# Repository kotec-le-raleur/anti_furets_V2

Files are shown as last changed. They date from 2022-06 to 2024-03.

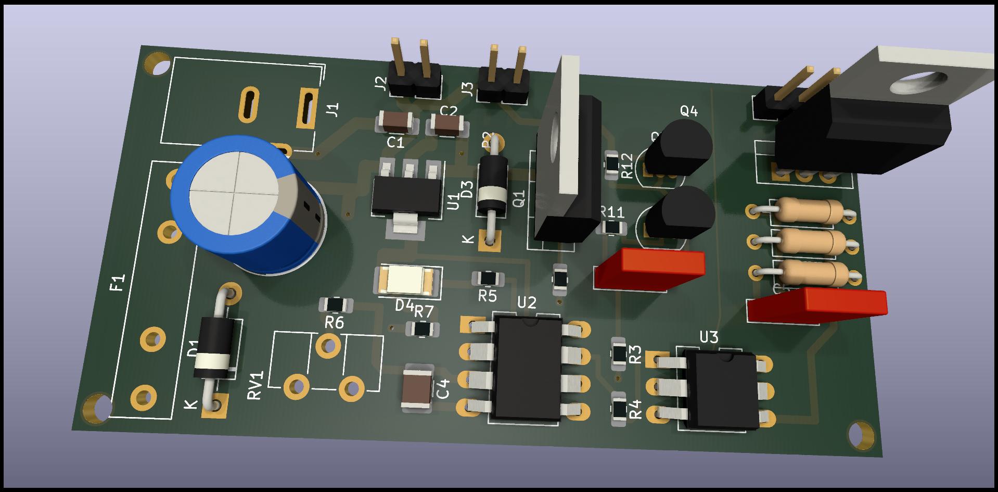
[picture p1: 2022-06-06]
Kicad_V6/anti_furets.jpg

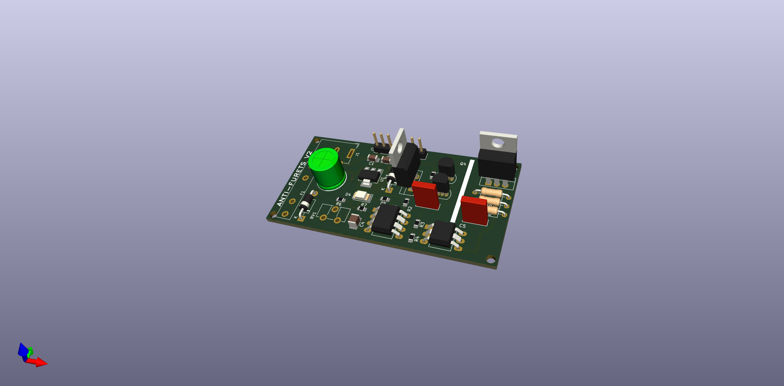
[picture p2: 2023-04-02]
Kicad_V6/anti_furets.png

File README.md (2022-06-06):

# anti_furets_V2
##  Anti_furets V2, avec plus de trucs super extra méga cools

* liste des ajouts:
  * un montage plus astucieux pour commander le HP Piézo ( genre de push-pull)
  * un opto-coupleur et triac  8A pour commander une grosse lampe ( coupure au zéro secteur avec un MOC3041)
  * un fusible sur le 12V
  * une carte 80X40 mm faite chez JLCPCB . Le luxe !

Dispositif générateur d'ultra-sons et de flashs lumineux pour effrayer les nuisibles dans un grenier

Ce petit montage trivial , garanti sans NE555, génére des suites aléatoires de sons dans la gamme des 15 à 22 kilo Hertz.   
Des flashs lumineux peuvent être ajoutés avec une ampoule LED 12V ou un ruban de leds.    
On peut aussi mettre un relais pour augmenter la puissance, mais il faudra que la charge et le relais supportent les marche/arret sans griller.   
La consommation sans l'ampoule LED est de 50 mA et une prise murale alim 12V suffit largement !   
Si une diode zéner est utilisée à la place du régulateur, vérifier que la tension à ses bornes ne dépasse pas 5V avant de plugger le µcontrôleur. 

Il faut penser à installer le core ATTiny85 qui implémente la fonction Tone() avant de compiler/télécharger le programme Ajouter dans le menu de l'IDE Arduino la ligne : http://drazzy.com/package_drazzy.com_index.json

Test en vrai: j'ai deux montages comme celui-là dans mon grenier depuis 2 ans !  
il faut bien le placer dans le chemin emprunté par les furets (ou fouines )  
J'ai ajouté des cubes de déodorants pour WC dans les passages et deux diffuseurs ambi-pur océan  (les plus puants )  
Ces saloperies de bestioles se sont barrés pour l'instant , mais la guerre contibue ....  
Bientôt les pièges électriques et mortels !  

A suivre

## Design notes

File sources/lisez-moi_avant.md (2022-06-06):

# Attention  
la carte a __completment changé__  
les pins I/O aussi, donc il se peut que le code soit __faux__ en ce qui concerne les N° de pins

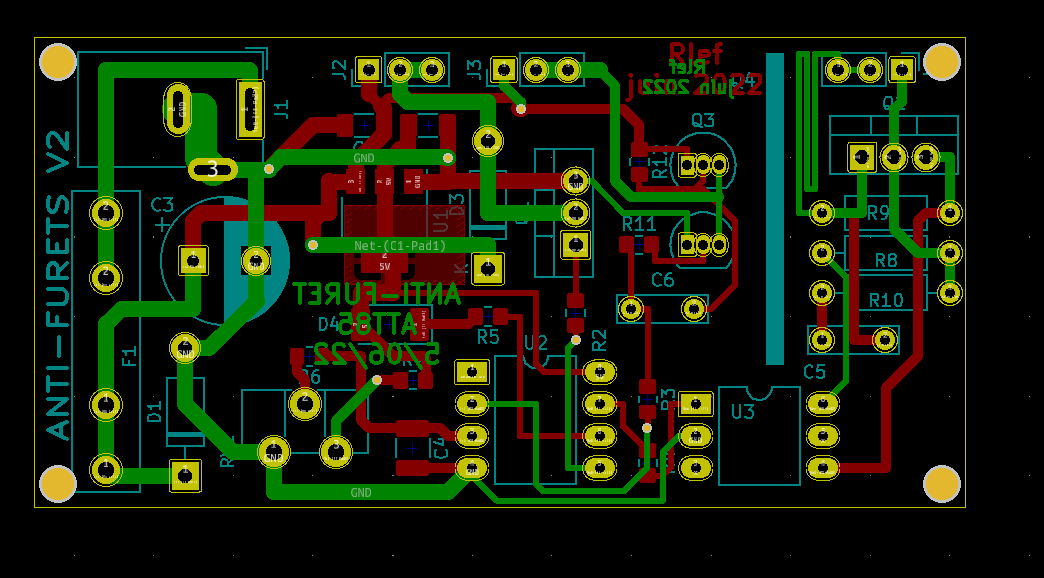
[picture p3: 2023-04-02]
antifurets.png

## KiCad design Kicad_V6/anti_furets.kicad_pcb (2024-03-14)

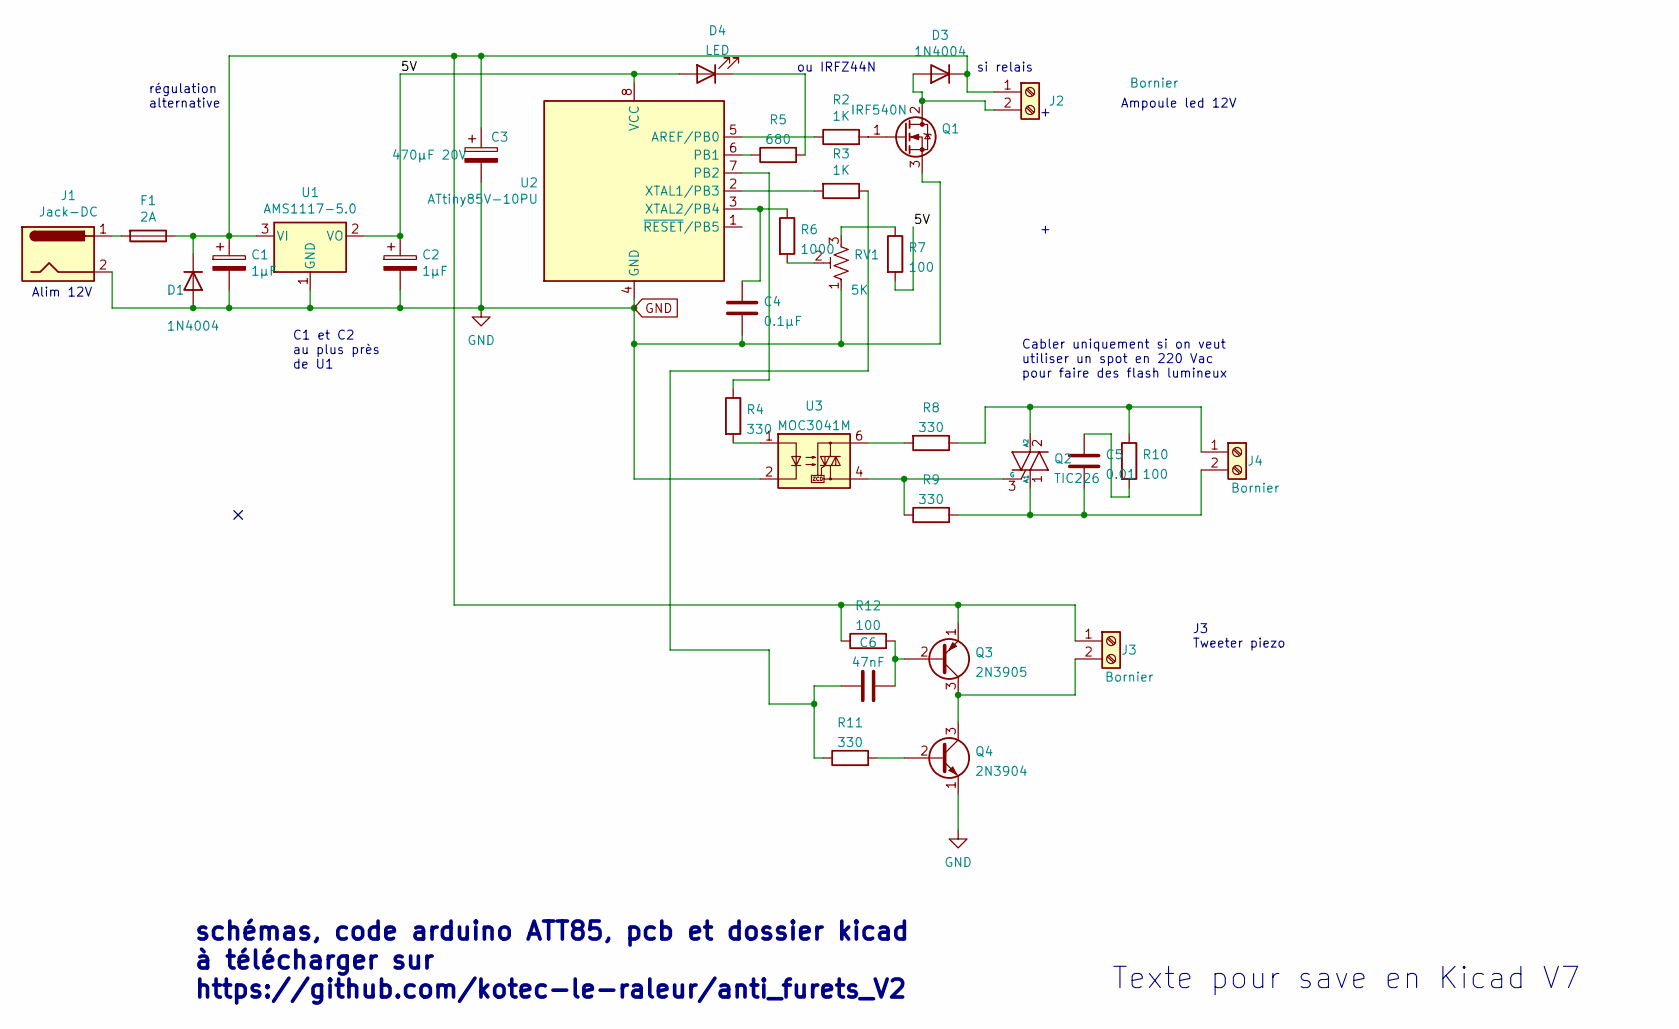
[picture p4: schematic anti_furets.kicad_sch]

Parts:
C1, C2: 1µF; C_1206_3216Metric_Pad1.33x1.80mm_HandSolder
C3: 470µF 20V; CP_Radial_D10.0mm_P5.00mm
C4: 0.1µF; C_1210_3225Metric_Pad1.33x2.70mm_HandSolder
C5: 0.01; C_Rect_L7.0mm_W2.0mm_P5.00mm
C6: 47nF; C_Rect_L7.0mm_W2.0mm_P5.00mm
D1, D3: 1N4004; D_DO-41_SOD81_P10.16mm_Horizontal
D4: LED; LED_2010_5025Metric_Pad1.52x2.65mm_HandSolder
F1: 2A; Fuseholder_Littelfuse_445_030_series_5x20mm
J1: Jack-DC; BarrelJack_Wuerth_6941xx301002
J2, J3, J4: Bornier; PinHeader_1x03_P2.54mm_Vertical
Q1: IRF540N; TO-220-3_Vertical
Q2: TIC226; TO-220-3_Vertical
Q3: 2N3905; TO-92_Inline
Q4: 2N3904; TO-92_Inline
R2, R3: 1K; R_0805_2012Metric_Pad1.20x1.40mm_HandSolder
R4, R11: 330; R_0805_2012Metric_Pad1.20x1.40mm_HandSolder
R5: 680; R_0805_2012Metric_Pad1.20x1.40mm_HandSolder
R6: 1000; R_0805_2012Metric_Pad1.20x1.40mm_HandSolder
R7, R12: 100; R_0805_2012Metric_Pad1.20x1.40mm_HandSolder
R8, R9: 330; R_Axial_DIN0207_L6.3mm_D2.5mm_P10.16mm_Horizontal
R10: 100; R_Axial_DIN0207_L6.3mm_D2.5mm_P10.16mm_Horizontal
RV1: 5K; Potentiometer_ACP_CA9-H3,8_Horizontal
U1: AMS1117-5.0; SOT-223-3_TabPin2
U2: ATtiny85V-10PU; DIP-8_W10.16mm_LongPads
U3: MOC3041M; DIP-6_W10.16mm_LongPads

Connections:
/5V: C2.1, D4.2 (A), R7.2, U1.2 (VO), U2.8 (VCC)
GND: C1.2, C2.2, C3.2, C4.2, D1.2 (A), J1.2, Q1.3 (S), Q4.1 (E), RV1.1, U1.1 (GND), U2.4 (GND), U3.2
unnamed: C1.1, C3.1, D1.1 (K), D3.1 (K), F1.1, J2.1, J3.1, Q3.1 (E), R12.1, U1.3 (VI)
unnamed: C4.1, R6.1, U2.3 (XTAL2/PB4)
unnamed: C5.1, R10.2
unnamed: C5.2, J4.2, J4.3, Q2.1 (A1), R9.2
unnamed: C6.1, R3.1, R11.1
unnamed: C6.2, Q3.2 (B), R12.2
unnamed: D3.2 (A), J2.2, J2.3, Q1.2 (D)
unnamed: D4.1 (K), R5.2
unnamed: F1.2, J1.1
unnamed: J3.2, J3.3, Q3.3 (C), Q4.3 (C)
unnamed: J4.1, Q2.2 (A2), R8.1, R10.1
unnamed: Q1.1 (G), R2.2
unnamed: Q2.3 (G), R9.1, U3.4
unnamed: Q4.2 (B), R11.2
unnamed: R2.1, U2.5 (AREF/PB0)
unnamed: R3.2, U2.2 (XTAL1/PB3)
unnamed: R4.1, U2.7 (PB2)
unnamed: R4.2, U3.1
unnamed: R5.1, U2.6 (PB1)
unnamed: R6.2, RV1.2
unnamed: R7.1, RV1.3
unnamed: R8.2, U3.6

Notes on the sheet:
Alim 12V
C1 et C2 au plus près de U1
Cabler uniquement si on veut utiliser un spot en 220 Vac pour faire des flash lumineux
schémas, code arduino ATT85, pcb et dossier kicad à télécharger sur https://github.com/kotec-le-raleur/anti_furets_V2
si relais
ou IRFZ44N
Texte pour save en Kicad V7
régulation alternative
J3 Tweeter piezo
Ampoule led 12V

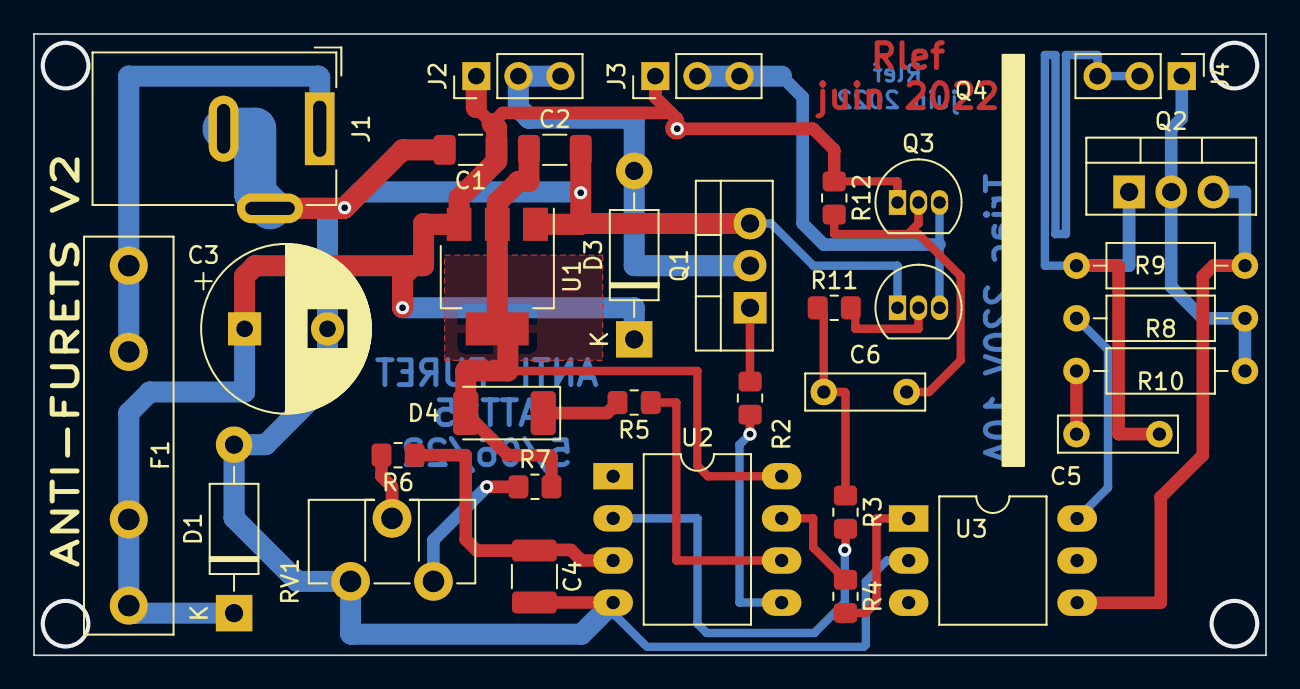
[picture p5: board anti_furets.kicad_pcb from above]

Board: 2 copper layers, 74.3 x 37.5 mm, 33 parts (0 on the bottom side), 24 nets.

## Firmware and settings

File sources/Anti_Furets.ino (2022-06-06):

//  René Lefebvre 6 decembre 2020

// programme chasse_furet
// Pour éloigner cette merde qui squatte le grenier (et qui chie partout)
// Un bon paquet d'ultra-son entre 13 kHz et 18 kHz (à la louche)
// en mode rafale aléatoire
// plus des flashs lumineux aléatoires eux aussi

// ATTENTION  la fonction tone() ne fonctionne pas avec tous les cores att85
// il faut installer le core suivant: http://drazzy.com/package_drazzy.com_index.json
//
// PINS    ATT85
//        ________U_______
//        | 1:RST  8: Vcc |
//        | 2:PB3  7: PB2 | 
//        | 3:PB4  6: PB1 | 
//        | 4:Gnd  5: PB0 | 
//        -----------------


  
    // PB5----pin 1 0 pin 8----Vcc
// A3  PB3----pin 2   pin 7----PB2 A1
// A2  PB4----pin 3   pin 6----PB1
    // Gnd----pin 4   pin 5----PB0
 
//  la tension lue sur A3 est convertie en valeur entre 0 et 1023
//  on multiple par 15 et cela sert de minimum pour la fréquence
//  quand on n'entend plus rien c'est que on est au choix : 
//					sourd, 
//					agé de plus de 60 ans, 
//					ou dans la gamme des ultra sons !
//
// mes chats ont bougé la tête à 20 m du HP, donc , ça fonctionne 
 
 
#define OUT_PIN PB4     // pin 3    vers la gate du 2N7000 pour le HP
#define AJUST_PIN PB3   // pin 2	vers le curseur du potentiometre  0..5V
#define LAMPE_PIN PB0   // pin 5    vers la gate du  IRFZ44 pour le spot

#define NB_FREQ 25

// les fréquences à zéro allument le spot lumineux
int Tab_FREQ[NB_FREQ]  = {100,200,345,0,550,700,850,0,952,1050,1250,1777,
                          1954,0,2154,2500,2750,3000,3300,0,3700,4050,4500,4990,0};
						  
int Tab_SILENCE[10]    = {20,50,80,100,250,300,450,500,750,800};
int Base = 10;     // Initialisation

//*******************  MAIN   *********************
void setup() {
  pinMode(OUT_PIN, OUTPUT);
  pinMode(LAMPE_PIN, OUTPUT);
 //Initialisation du random avec la clé universelle
  randomSeed(42);     
}

//*******************  LOOP   *********************
void loop() {
int i=0;
long frq, tp;
for (i=0;i<10;i++)
    {
	Base = analogRead(AJUST_PIN) * 15;
    frq  = random(NB_FREQ);
    tp   = random(10);
	if (Tab_FREQ[frq] > 0)
	    {
        tone(OUT_PIN, Tab_FREQ[frq]+ Base );
        delay(Tab_SILENCE[tp]);
        // noTone();
        }
	  else				// fréquence = 0 : on allume le spot
		{
        tone(OUT_PIN, Tab_FREQ[frq-1]+ Base );
		digitalWrite(LAMPE_PIN,HIGH);  
	    delay(Tab_SILENCE[tp]+100);
		digitalWrite(LAMPE_PIN,LOW);  
	    //  noTone();
		}
   }
}
//  
// Rien de plus pour ce code trivial
   
